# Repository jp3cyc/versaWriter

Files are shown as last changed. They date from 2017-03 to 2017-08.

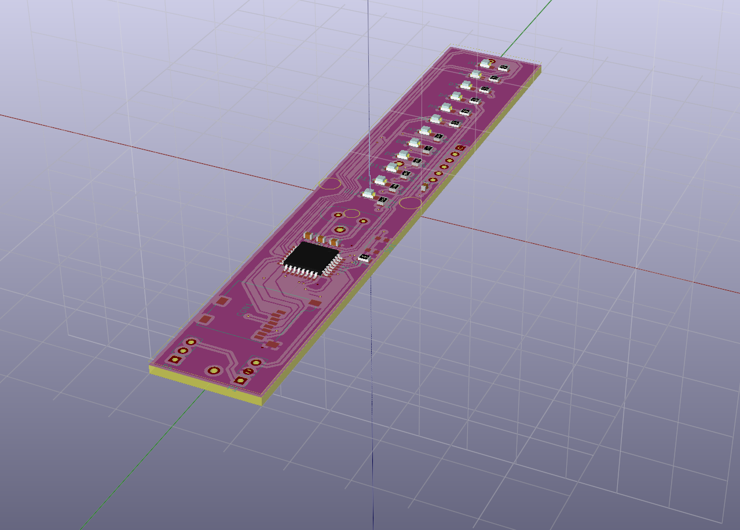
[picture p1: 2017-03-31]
circuit/verseWriter.png

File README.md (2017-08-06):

# versaWriter
バーサライター
microSDを用いることで，様々なパターンを保存することができます．

- verseWriter-cache.lib ライブラリファイル
- verseWriter.bak バックアップファイル
- verseWriter.kicad_pcb 基板データ
- verseWriter.pdf 回路図データpdf版
- verseWriter.pro KiCadプロジェクトファイル
- verseWriter.sch 回路図データ

# KiCadについて
KiCad 4.0.0を使用しています．
ライブラリは標準ライブラリのみを使用しています．

# 部品の購入について
大体の部品は秋月電子で購入できます．
秋月で購入する際はAkiCartを使うと一括で部品をカートに入れることができます．
http://aki.prioris.jp/list/b79d8ac9-18c4-4d1a-af78-d3021e4c269e/

# LEDについて
LEDの数は24個使っています．
8個x3でダイナミック点灯しています

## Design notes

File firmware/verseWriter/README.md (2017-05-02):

# プログラムの書き込み方法

このバーサライタはシリアル経由での書き込みが何故かできません．
そのため，ISP経由の書き込みをおこないます．

ISP経由の書き込みの方法を次に示します．

# インストール編

- avrdudeをインストールして，PATHを設定します．ArduinoIDEをインストールすると一緒に書き込まれているかも
- ArduinoIDEの設定を変更して，hexファイルを出力する設定に変更します．http://d.hatena.ne.jp/licheng/20130826/p1 この設定の時出力するファイル専用のディレクトリを作成してください．コンパイルのたびにフォルダ内をすべて削除するので，デスクトップに設定するとコンパイルのたびにデスクトップのファイルを全て削除してくれます．デスクトップ以下にディレクトリを作りましょう．

# 書き込み編
- コマンドプロンプトを起動
- hexファイルのあるディレクトリまでcdコマンドを使って移動
- derコマンドをつかって，.hexで終わるファイルを探す
- verseWriter.cpp.hexだったとします．そのときには次のコマンドを打ち込みます．（まだEnterはおさない）

avrdude -c avrisp -P COM9 -b 19200 -p m328p -U flash:w:verseWriter.cpp.hex

- ArduinoISPを書き込んだArduinoにISP変換シールドを乗せます．
- ArduinoISPをパソコンと接続した後，バーサライタの電源を入れて，Arduinoシールドとバーサライタを接続します
- コマンドプロンプトでEnterを押して書き込みます

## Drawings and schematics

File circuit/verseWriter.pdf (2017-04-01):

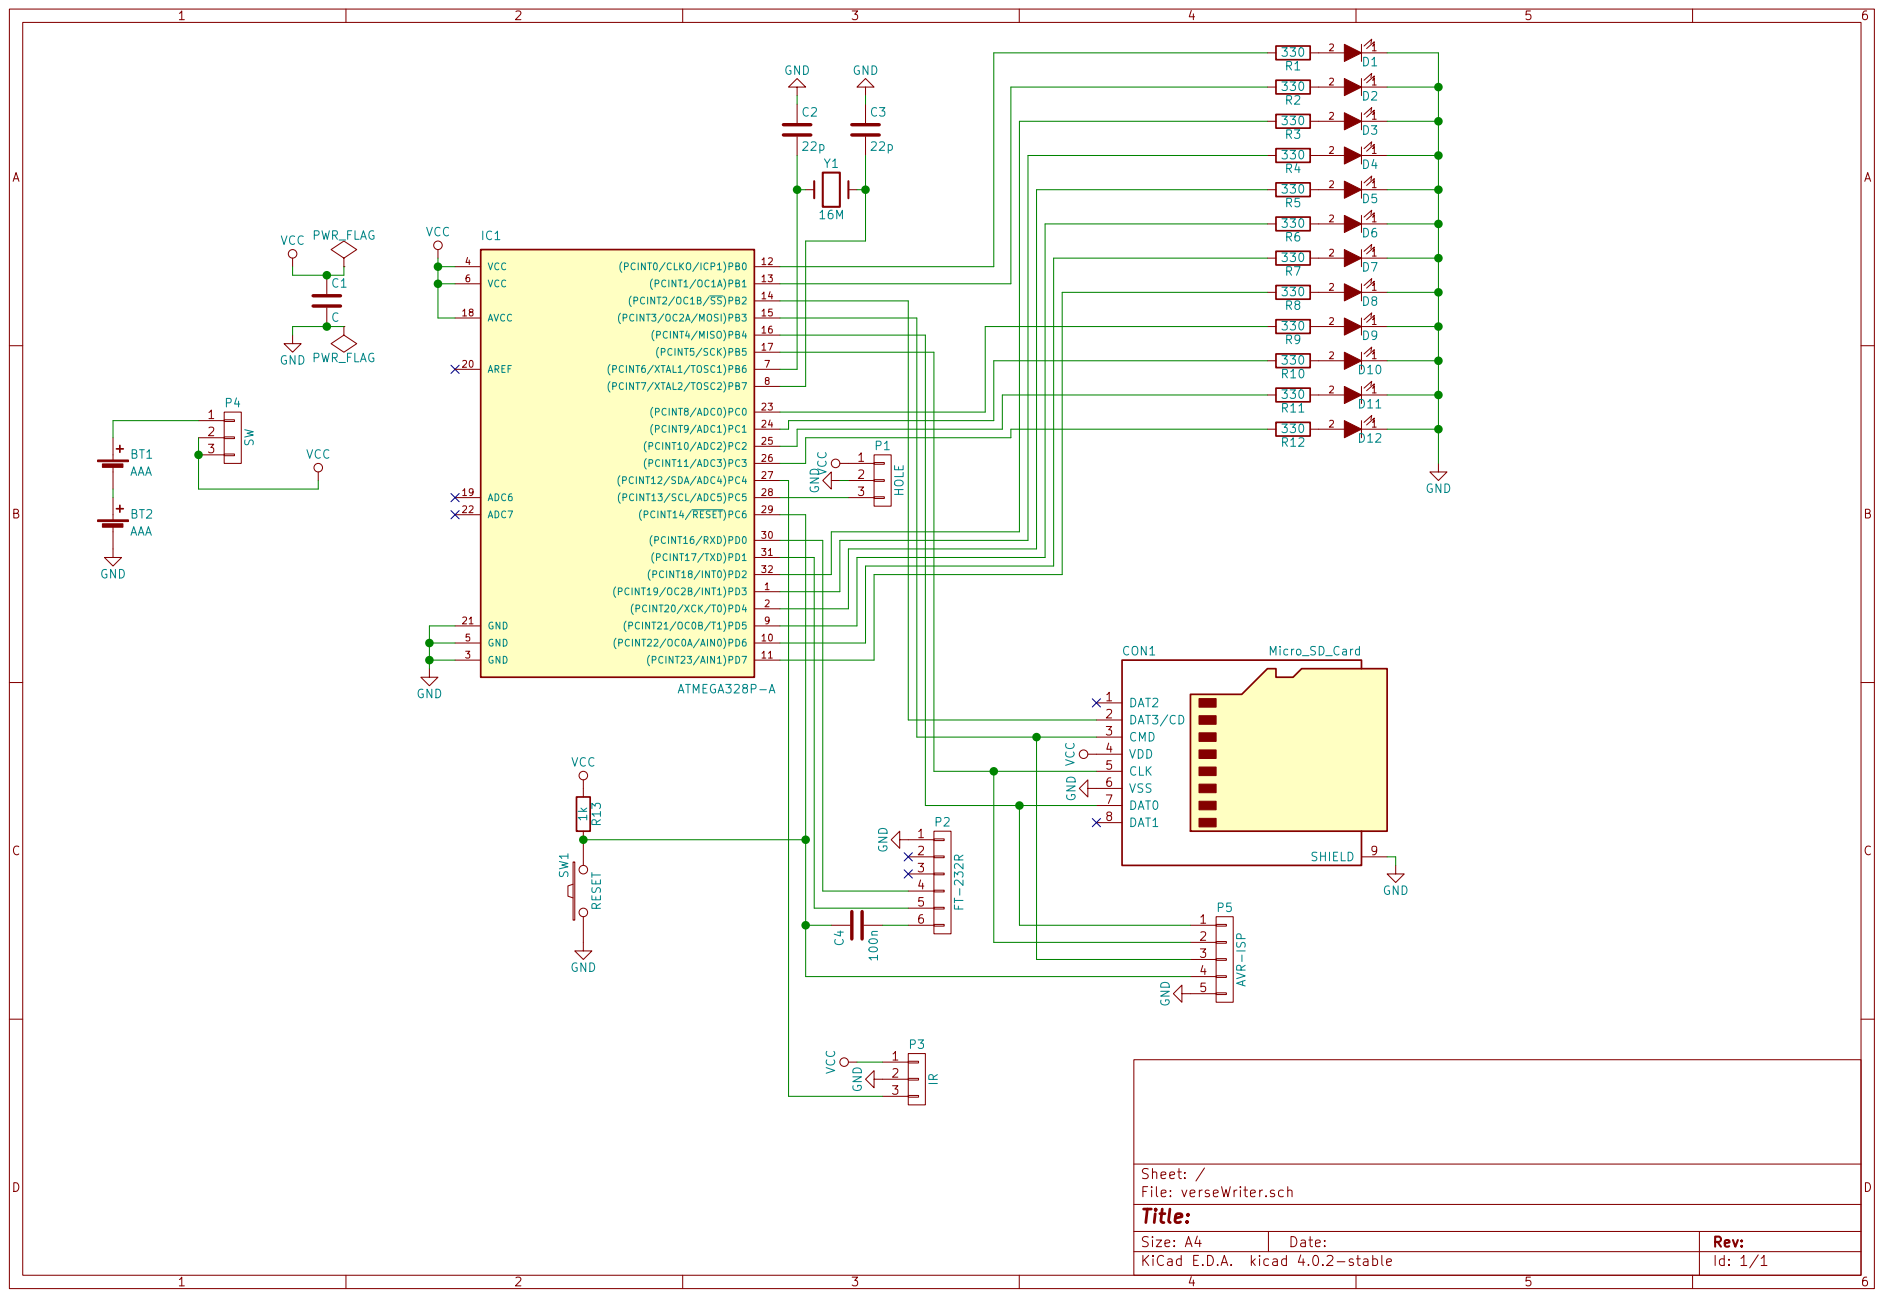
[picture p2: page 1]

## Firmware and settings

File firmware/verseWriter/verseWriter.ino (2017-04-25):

//#include <MsTimer2.h>
#include <TimerOne.h>

int pinLED0 = 8;
int pinLED1 = 9;
int pinLED2 = 2;
int pinLED3 = 3;
int pinLED4 = 4;
int pinLED5 = 5;
int pinLED6 = 6;
int pinLED7 = 7;
int pinLED8 = 14;
int pinLED9 = 15;
int pinLED10 = 16;
int pinLED11 = 17;

int pinHole = 18;
int pinIr = 19;

volatile unsigned long time = 1;
volatile unsigned long timer = 0;
volatile unsigned int posi=0;
volatile unsigned long cnt=0;
int count = 0;

int flag=1;

unsigned int pattern[] = {  // 点灯パターン
0b000011000000,
0b000011000000,
0b000011100000,
0b000011100000,
0b000001110000,
0b000000111000,
0b000000011110,
0b000000000100,
0b000000000000,
0b000000000000,
0b000000000000,
0b000000000000,
0b000000000100,
0b000000011110,
0b000000111100,
0b000001110000,
0b000011100000,
0b000011100000,
0b000011000000,
0b000011000000,
0b000011000000,
0b000011000000,
0b000011100000,
0b000011100000,
0b000011110000,
0b000011111000,
0b000111011111,
0b000111000110,
0b000111000000,
0b000111000000,
0b000111000000,
0b000111000000,
0b000111000000,
0b000111000000,
0b000011000000,
0b000011000000,
0b000011000000,
0b000011000000,
0b000011000000,
0b000011000000,


};



void setup()
{
  pinMode(pinLED0, OUTPUT);
  pinMode(pinLED1, OUTPUT);
  pinMode(pinLED2, OUTPUT);
  pinMode(pinLED3, OUTPUT);
  pinMode(pinLED4, OUTPUT);
  pinMode(pinLED5, OUTPUT);
  pinMode(pinLED6, OUTPUT);
  pinMode(pinLED7, OUTPUT);
  pinMode(pinLED8, OUTPUT);
  pinMode(pinLED9, OUTPUT);
  pinMode(pinLED10, OUTPUT);
  pinMode(pinLED11, OUTPUT);

  pinMode(pinHole, INPUT);
  pinMode(pinIr, INPUT);

  //タイマ割り込みの設定
  Timer1.initialize(20); // micro second
  Timer1.attachInterrupt(timerInterrupt);
  Timer1.start();

}

void ledWrite(unsigned int signal){
  
  //ポートに出力している．digitalWriteを高速化する書き方をしている
  // 0x800 is center.LED1 is outside.
  PORTB = PORTB & 0xfc | (signal & 0x003);
  PORTD = PORTD & 03 | (signal & 0x0fc) ; 
  PORTC = PORTC & 0xf0 | (signal & 0x0f00) >> 8;

}
void checkPinInterrupt(){
  //ホールセンサの立ち上がりを研修tしている．
  if(( (PINC & 0x10) == 0x10 ) && ( flag == 1) ){  //立ち上がりのときに１度だけ実行
    PinInterrupt();
    flag = 0;


  }
  if( ((PINC & 0x10) != 0x10) && (flag == 0) ){
    flag = 1;
  }

}

void PinInterrupt(){
  //立ち上がりのときに実行される
  
  //位置の初期化
  posi=0;

    // 点灯時間計算
   count ++;
   if(count >= 10 ){      // 回転数は10回の平均をとる
   time = timer / 400;    // 1周は40コマだから400
   timer = 0;
   count = 0;
   }
}

void timerInterrupt(){
  //20マイクロ秒ごとに実行される．
  timer ++;
  cnt ++;
}


void loop(){
  //checkPinInterrupt();

  checkPinInterrupt();      //ホール素子をチェック
  ledWrite(pattern[posi]);  //LEDを点灯させる
  posi ++;                  
  if(posi >=40) {            //1周したときのしょり
    posi =  0;
  }


  while(1){                  //待つ．待っているときにもホール素子をチェックする．
    checkPinInterrupt();
    if( cnt >= time ){
      cnt = 0;
      break;
    }
  }

}

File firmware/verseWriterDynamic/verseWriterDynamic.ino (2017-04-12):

int pinLED0 = 2;
int pinLED1 = 3;
int pinLED2 = 4;
int pinLED3 = 5;
int pinLED4 = 6;
int pinLED5 = 7;
int pinLED6 = 8;
int pinLED7 = 9;

int pinDynamic0 = 14;
int pinDynamic1 = 15;
int pinDynamic2 = 16;

int pinHole = 19;

int time = 100;

bool yonple[580] ={};
int pos = 0;
void setup()
{
  

  for(int i=0;i<24;i++){
    for(int j=0;j<24;j++){
      if(j==i)yonple[i*24+j]=1;
      else yonple[i*24+j]=0;
    }
  }
  
  pinMode(pinLED0, OUTPUT);
  pinMode(pinLED1, OUTPUT);
  pinMode(pinLED2, OUTPUT);
  pinMode(pinLED3, OUTPUT);
  pinMode(pinLED4, OUTPUT);
  pinMode(pinLED5, OUTPUT);
  pinMode(pinLED6, OUTPUT);
  pinMode(pinLED7, OUTPUT);
  
  pinMode(pinDynamic0, OUTPUT);
  pinMode(pinDynamic1, OUTPUT);
  pinMode(pinDynamic2, OUTPUT);
  
  pinMode(pinHole, INPUT);
  
  
}

void sample(bool *ptr)
{
  int test =1;  
  for(int i=0;i<3;i++){
    
    //PORTC = PORTC & 0xF8 | (0x01 << i) ;
    //PORTC = (0x07 & (i<<1));
   
    int d = 0;
    int b = 0;
    for(int j=0;j<8;j++){
      d = (d<<1)|((*(ptr+ j*3+i))?1:0);
      b = (b<<1)|((*(ptr+ j*3+i))?1:0);
    }

 
    PORTD=(PORTD & 0x03) | (d & 0xFC);
    PORTB=(PORTB & 0xFC) | (b & 0x03);
  }
}

void loop() {
  // put your main code here, to run repeatedly:
    
  
  sample(yonple+24*pos);
  delay(100);
  pos+=1;
  if(pos==24)pos=0;
  
}

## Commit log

2017-03-06 配線変更
    [verseWriter.kicad_pcb, verseWriter.sch]
2017-03-27 Add AVR-ISP
    [_saved_verseWriter.sch, verseWriter.kicad_pcb, verseWriter.sch]
2017-04-01 PCBgogo発注
    [verseWriter.kicad_pcb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]
2017-04-01 マスクを追加
    [aboutLEDResister.csv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]
2017-04-12 プログラムを追加
    [verseWriter.drl]
2017-04-12 ファイル名を変更
    ダイナミック点灯のプログラム
2017-04-13 とりあえず動作
2017-04-17 動作確認用
2017-04-17 一周の時間がうまく計測できていない
    それ以外はOK
2017-04-18 とりあえず動作する．1列の時間の設定を要調整
2017-04-18 バグは残っているが完成
2017-04-19 動作した
    3.1Vのときに文字がでてきた．でも，回転数が遅いため鮮明に見えない欠点がある．
2017-04-19 tを表示させることに成功@6V
2017-04-20 完成
    初期化が不安定なので，回路的に修正する必要がある
2017-04-20 20ms割り込みに変更
2017-04-25 コメントを追加
2017-05-02 書き込み方法の説明を追加
2017-05-02 40分割時の点灯パターンを追加
2017-08-06 AkiCartのURLを追加
